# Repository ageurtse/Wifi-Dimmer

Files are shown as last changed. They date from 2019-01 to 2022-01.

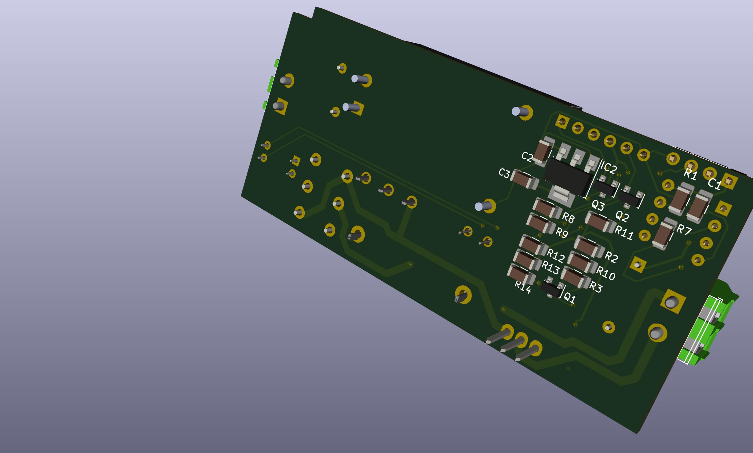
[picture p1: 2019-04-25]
New Dimmer 3d-bottom.jpg

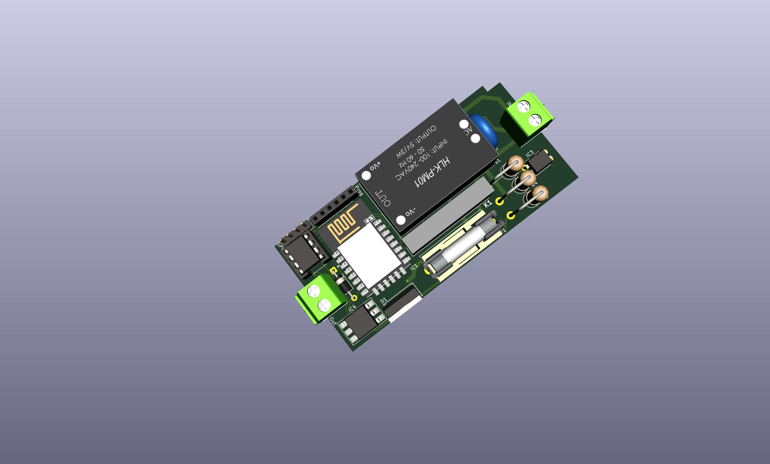
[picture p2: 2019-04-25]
New Dimmer 3d-1.jpg

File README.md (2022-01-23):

# Wifi Dimmer

!!!!! Please do not rebuild this device, in my case there was a serious issue with overheating !!!!!

This is all about my home build WiFi Dimmer
Becaus of it's my first github project, the master is still in Beta. 
For me the project works, but there are a lot off things to change, so keep watching for any change.

11-3-2019, final version, the hard and software is ready to use. 
soon i wil post a youtube movie from live controlling a light. 

3d view 1

This is version 2, in the past i build a differt version which is not exactly what i want. 
Version 2 is one which fit in a simpel housing. 

There are 2 parts of the software, one for the ATTiny and one for the ESP8266
Both are posted here. 
# Word of Caution
Please be very carefull you are working with live voltage 230V, this voltage can realy harm you. 
By building the dimmer, i'm not responsible for any faults or what ever. I stoped development off this dimmer, on one night the triax was overheated. luckely i was at home to prevented real major damage. 

# ATtiny85 Software
The ATtiny85 software is for the soul purpose of dimming the light, there is a zerocross detction which is on interupt 0, the gate is on pin PB3. 
The communication with the main processor is done by softserial. 
The code is based on the forum post at arduino : https://forum.arduino.cc/index.php?topic=314773.0

# ESP8266 software
The main software for the ESP12 module is build with arduino, the wifi and custom settings can be done with the great library from Hieromon https://github.com/Hieromon/AutoConnect
After fist flash by serial, all next updates could be down by browser. 
find the IP-adres or host name and add /update to get to the update page. 
To alter wifi setting's and in the futher mqtt settings and i hope a lot more add /_ac

The file makes use of some thirth party library's which can be found here :
AutoConnect : https://github.com/Hieromon/AutoConnect
PageBuilder : https://github.com/Hieromon/PageBuilder
ArduinoJson : https://arduinojson.org/ version 5

# The hardware
For the main board there is a small mistake made with the Triac, there where 2 wires changes. A1 and A2 need to be turned. 
In a next updat of the print i will fix that, for now i just solderd 2 wires and cross connect them to te pcb.

Also the Fuse holder is to large, i bought a pcb fuse now it all fits well.

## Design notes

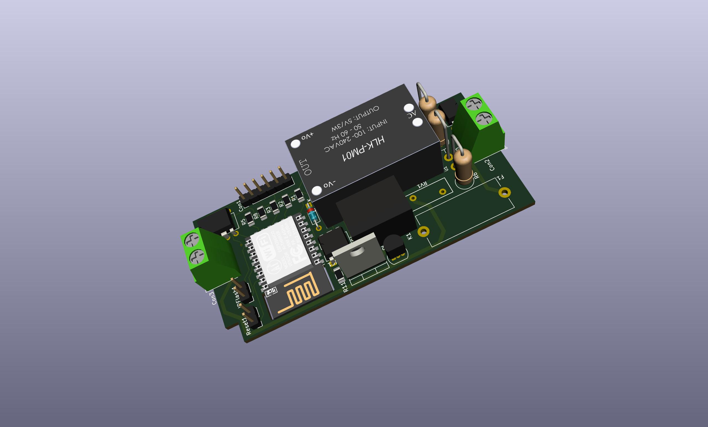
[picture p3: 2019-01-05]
Kicad files/3d view 2.jpg

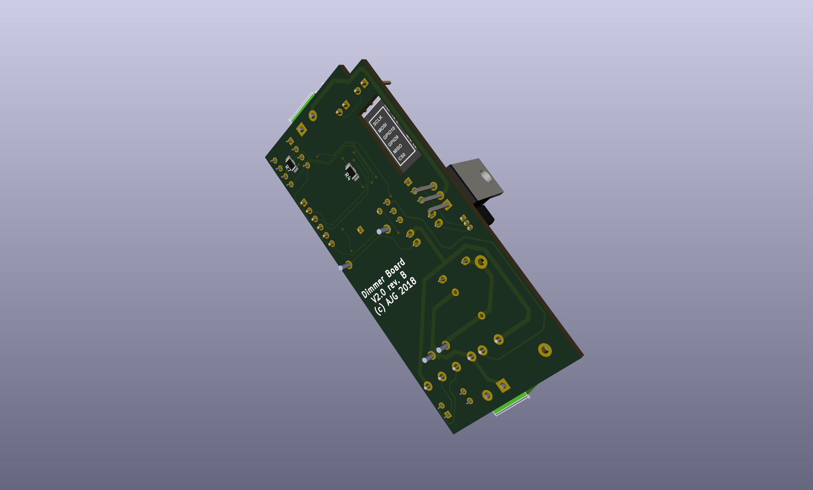
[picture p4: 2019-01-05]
Kicad files/3d view bottom.jpg

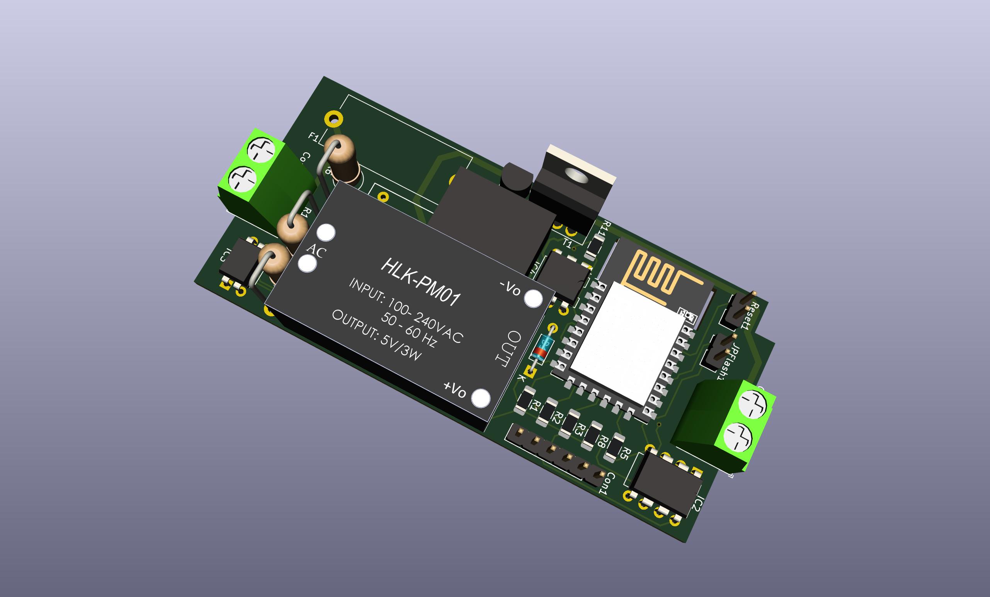
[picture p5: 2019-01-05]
Kicad files/3d view 1.jpg

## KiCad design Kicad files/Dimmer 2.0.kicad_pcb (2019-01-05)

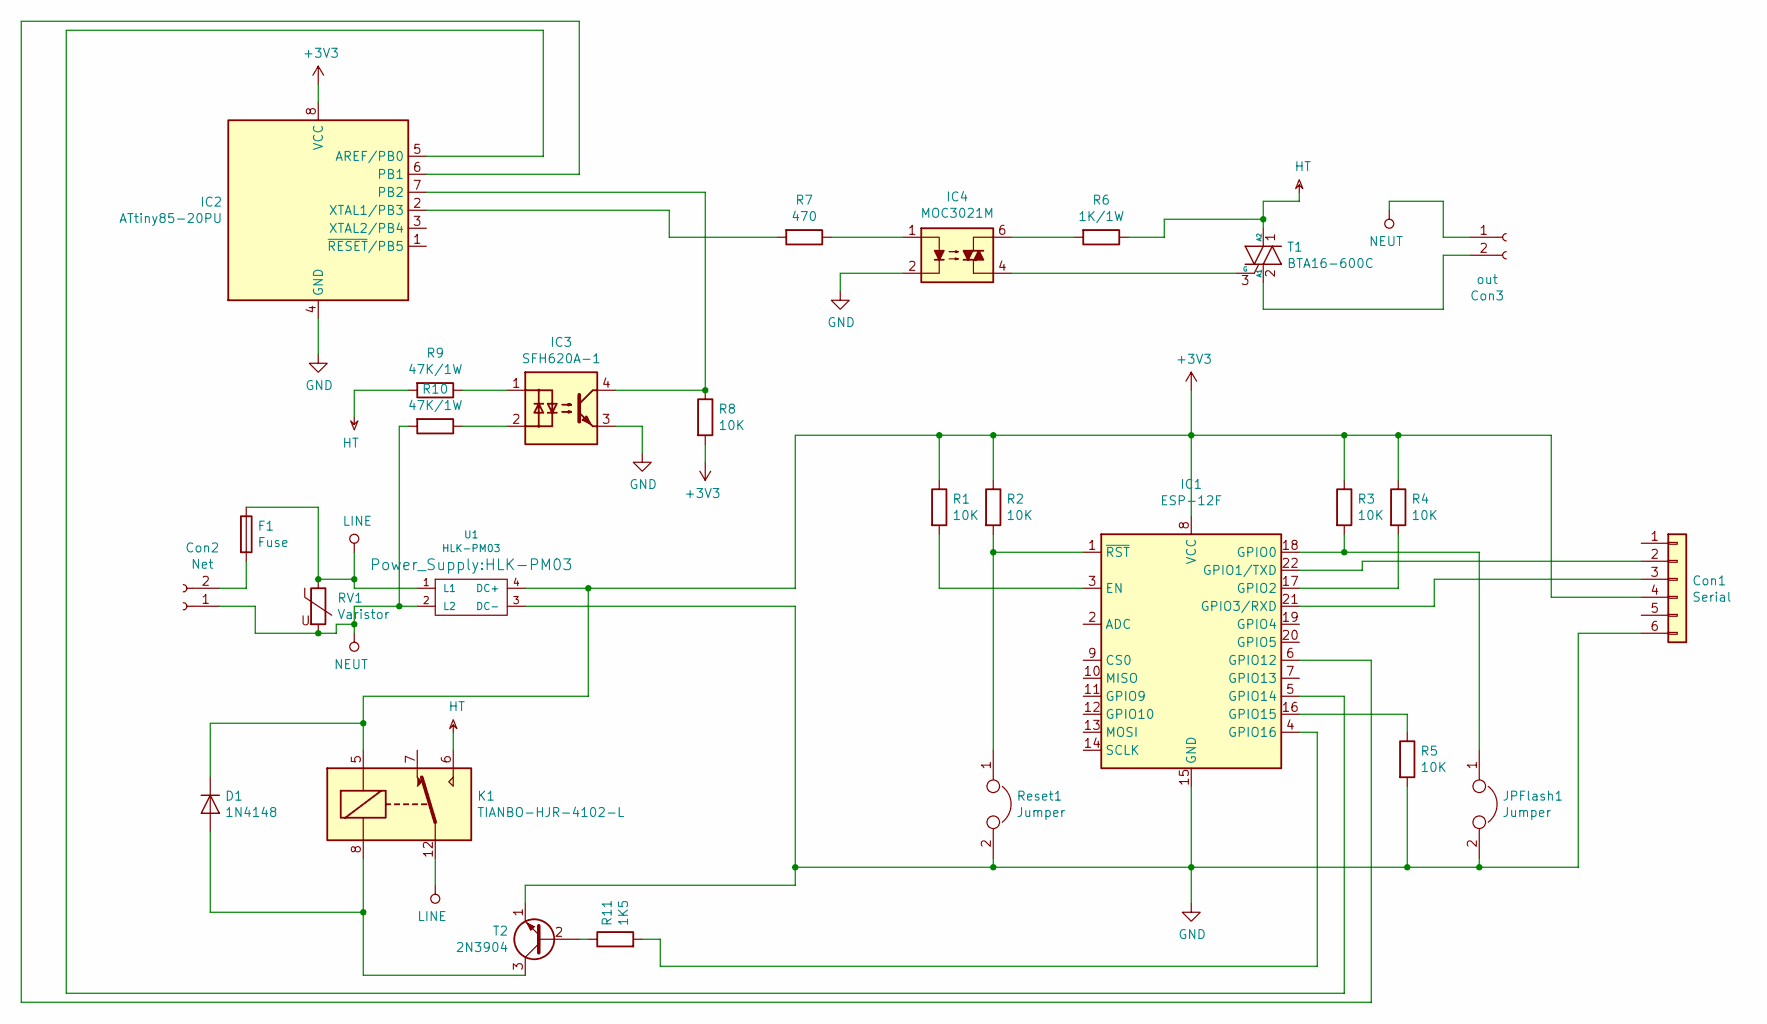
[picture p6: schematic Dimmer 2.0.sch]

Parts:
Con1: Serial; PinHeader_1x06_P2.54mm_Vertical
Con2: Net; TerminalBlock_Phoenix_PT-1,5-2-5.0-H_1x02_P5.00mm_Horizontal
Con3: out; TerminalBlock_Phoenix_PT-1,5-2-5.0-H_1x02_P5.00mm_Horizontal
D1: 1N4148; D_DO-35_SOD27_P7.62mm_Horizontal
F1: Fuse; Fuseholder_Cylinder-5x20mm_Stelvio-Kontek_PTF78_Horizontal_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
IC1: ESP-12F; ESP-12E
IC2: ATtiny85-20PU; DIP-8_W7.62mm
IC3: SFH620A-1; DIP-4_W7.62mm
IC4: MOC3021M; DIP-6_W7.62mm
JPFlash1: Jumper; PinHeader_1x02_P2.54mm_Vertical
K1: TIANBO-HJR-4102-L; Relay_SPDT_HJR-4102
R1, R2, R3, R4, R5, R8: 10K; R_1206_3216Metric_Pad1.42x1.75mm_HandSolder
R6: 1K/1W; R_Axial_DIN0414_L11.9mm_D4.5mm_P5.08mm_Vertical
R7: 470; R_1206_3216Metric_Pad1.42x1.75mm_HandSolder
R9, R10: 47K/1W; R_Axial_DIN0414_L11.9mm_D4.5mm_P5.08mm_Vertical
R11: 1K5; R_1206_3216Metric_Pad1.42x1.75mm_HandSolder
RV1: Varistor; RV_Disc_D12mm_W4.8mm_P7.5mm
Reset1: Jumper; PinHeader_1x02_P2.54mm_Vertical
T1: BTA16-600C; TO-220-3_Vertical
T2: 2N3904; TO-92_Inline
U1: HLK-PM03

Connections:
+3V3: Con1.4, D1.1 (K), IC1.8 (VCC), IC2.8 (VCC), K1.5, R1.1, R2.1, R3.1, R4.1, R8.2, U1.4 (DC+)
GND: Con1.6, IC1.15 (GND), IC2.4 (GND), IC3.3, IC4.2, JPFlash1.2, R5.2, Reset1.2, T2.1 (E), U1.3 (DC-)
HT: K1.6, R6.1, R9.2, T1.1 (A2)
LINE: F1.1, K1.12, RV1.1, U1.1 (L1)
NEUT: Con2.1, Con3.1, R10.2, RV1.2, U1.2 (L2)
unnamed: Con1.2, IC1.22 (GPIO1/TXD)
unnamed: Con1.3, IC1.21 (GPIO3/RXD)
unnamed: Con2.2, F1.2
unnamed: Con3.2, T1.2 (A1)
unnamed: D1.2 (A), K1.8, T2.3 (C)
unnamed: IC1.1 (~RST), R2.2, Reset1.1
unnamed: IC1.3 (EN), R1.2
unnamed: IC1.4 (GPIO16), R11.2
unnamed: IC1.5 (GPIO14), IC2.5 (AREF/PB0)
unnamed: IC1.6 (GPIO12), IC2.6 (PB1)
unnamed: IC1.16 (GPIO15), R5.1
unnamed: IC1.17 (GPIO2), R4.2
unnamed: IC1.18 (GPIO0), JPFlash1.1, R3.2
unnamed: IC2.2 (XTAL1/PB3), R7.2
unnamed: IC2.7 (PB2), IC3.4, R8.1
unnamed: IC3.1, R9.1
unnamed: IC3.2, R10.1
unnamed: IC4.1, R7.1
unnamed: IC4.4, T1.3 (G)
unnamed: IC4.6, R6.2
unnamed: R11.1, T2.2 (B)

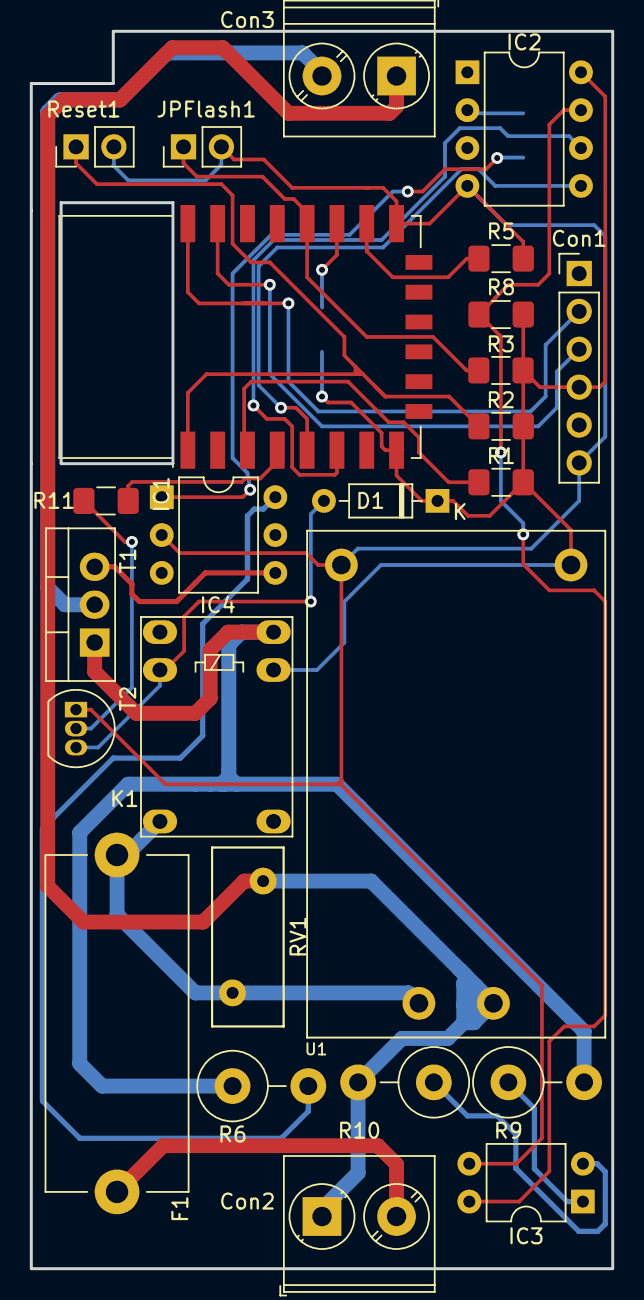
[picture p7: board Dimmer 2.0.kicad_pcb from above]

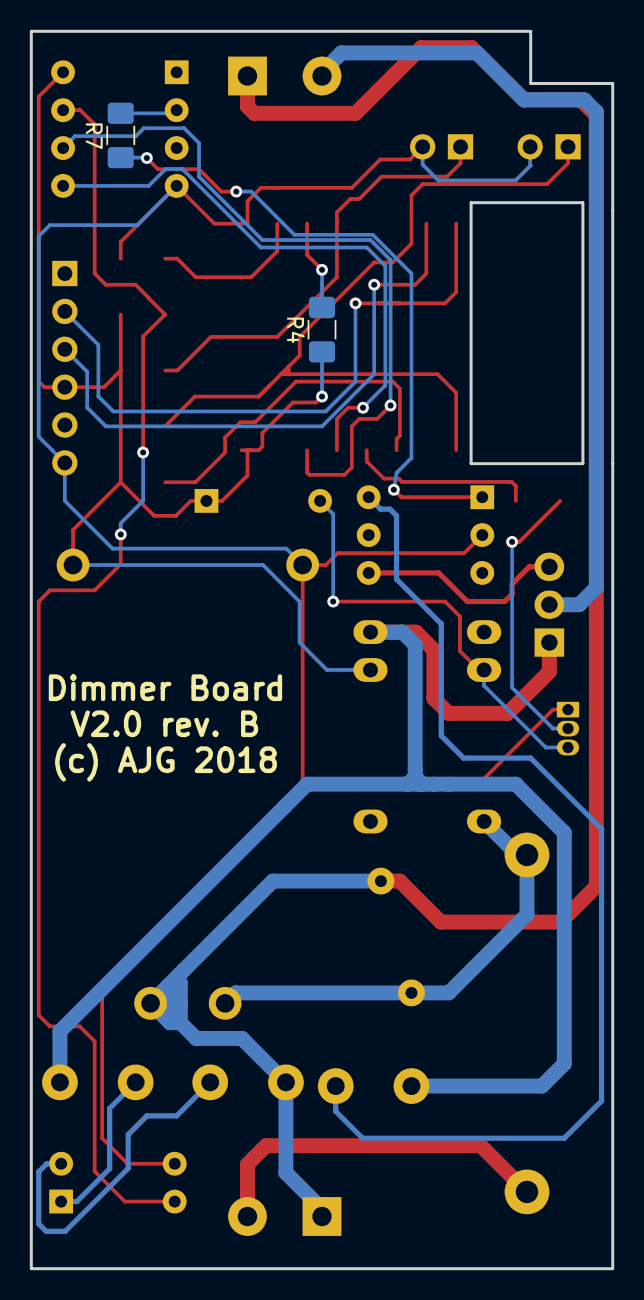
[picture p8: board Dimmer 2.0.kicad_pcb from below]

Board: 2 copper layers, 39.0 x 83.0 mm, 27 parts (2 on the bottom side), 26 nets.

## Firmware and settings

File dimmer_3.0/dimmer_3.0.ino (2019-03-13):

#include <ESP8266WiFi.h>
#define GET_CHIPID()  (ESP.getChipId())
#include <ESP8266HTTPUpdateServer.h>
#include <PubSubClient.h>
#include <AutoConnect.h>
#include <ESP8266HTTPUpdateServer.h>
#include <FS.h>    
#include <SoftwareSerial.h>

#define RX                    14
#define TX                    12
SoftwareSerial DimSerial(RX,TX,false,256); // RX, TX

// ESP8266 webserver
ESP8266WebServer  webServer;
//Autoconnect wifi manager
AutoConnect  portal(webServer);
AutoConnectAux update("/update", "Update");
AutoConnectConfig config;
// MQTT Stuf
WiFiClient   wifiClient;
PubSubClient mqttClient(wifiClient);
// updating
ESP8266HTTPUpdateServer UpdateServer;

#include "declarations.h"
#include "Dimmath.h"
#include "filehandeling.h"
#include "webpages.h"
#include "mqtt.h"

void setup() {
  delay(1000);
  Serial.begin(115200);
  Serial.println();

  pinMode(led_pin, OUTPUT);
  pinMode(relay_pin, OUTPUT);

  //allows serving of files from SPIFFS
  Serial.println("Mounting FS...");
  if (!SPIFFS.begin()) {
    Serial.println("Failed to mount file system");
    return;
  }
  if (loadConfiguration("/config.json", dimconfig)) {
    Serial.println("Config read");
  }
  // Dump config file
  Serial.println(F("Print config file after reading..."));
  printFile(fileName);

  config.apid = String("ESP") + String(GET_CHIPID(), HEX);

  if (dimconfig.devicename != "") {
    config.apid = dimconfig.devicename;
    config.hostName = dimconfig.devicename;
    Serial.println(F("Set custom name"));
  }

  Serial.print("APID : ");
  Serial.println(config.apid);
  
  config.bootUri = AC_ONBOOTURI_HOME;
  config.homeUri = "/";
  
  webServer.on("/saveDim", saveSetting);  // Register /feels handler
  webServer.on("/", handleRoot);
  
  portal.load(settings);
  portal.on("/Settings",settingsOn, AC_EXIT_AHEAD);
  portal.join ({update});
  portal.config(config);

  UpdateServer.setup(&webServer);

  Serial.print("WiFi ");
  if (portal.begin()) {
    Serial.println("connected:" + WiFi.SSID());
    Serial.println("IP:" + WiFi.localIP().toString());
  } else {
    Serial.println("connection failed:" + String(WiFi.status()));
    while (1) {
      delay(100);
      yield();
    }
  }

  if (dimconfig.mqttServer != "") {
    mqttClient.setServer(dimconfig.mqttServer.c_str(), 1883);
    mqttClient.setCallback(callback);  
  }

  digitalWrite(led_pin, HIGH);
  digitalWrite(relay_pin, LOW);
  delay(1000);
  digitalWrite(led_pin, LOW);
  digitalWrite(relay_pin, HIGH);
}


void loop() {
  portal.handleClient();

  if (dimconfig.mqttServer != "") {
    if (!mqttClient.connected()) {
      reconnect();
    }
    mqttClient.loop();
  }
}

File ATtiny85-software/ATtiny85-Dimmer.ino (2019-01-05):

// Voltage controlled dimmer with ATtiny85
//
// This arduino sketch includes a zero
// crossing detect function and an opto-isolated triac.
//
// AC Phase control is accomplished using the internal
// hardware timer1 in the ATtiny85
//
// Timing Sequence
// * timer is set up but disabled
// * zero crossing detected
// * timer starts counting from zero
// * comparator set to "delay to on" value
// * counter reaches comparator value
// * comparator ISR turns on triac gate
// * counter set to overflow - pulse width
// * counter reaches overflow
// * overflow ISR turns off triac gate
// * triac stops conducting at next zero cross

// The hardware timer runs at 1MHz (3mA).
// A half period of a 50Hz AC signal takes 10 ms is 10000 counts.
// @ 1MHZ (3ma)prescaler (1000) 128 78 counts per half period

#include <avr/io.h>
#include <avr/interrupt.h>
#include <SoftwareSerial.h>


#define DETECT PB2      //zero cross detect, interrupt 0
#define GATE PB3        //triac gate is physical
#define PULSE 4       	//trigger pulse width 4

#define RX    PB1   		//Serial port RX
#define TX    PB0   		//Serial port TX
SoftwareSerial Serial(RX, TX);

int dimvalue;			//After startup, turn off light;

void setup(){

  delay (9000);								//Wait for booting the ESP8266

	// set up pins
  pinMode(DETECT, INPUT);      //zero cross detect
  digitalWrite(DETECT, HIGH);  //enable pull-up resistor
  pinMode(GATE, OUTPUT);       //triac gate control


  //If all goes well, the light will flash several time, to notify the user
  digitalWrite(GATE, HIGH);
  delay(500);
  digitalWrite(GATE, LOW);
  delay(500);
  digitalWrite(GATE, HIGH);
  delay(500);
  digitalWrite(GATE, LOW);
  delay(500);
  digitalWrite(GATE, HIGH);


  // set up Timer1
  TCCR1 = 0;     											// stop timer
  OCR1A = dimvalue;										// set initial dim value
  TIMSK = _BV(OCIE1A) | _BV(TOIE1);  	// interrupt on Compare Match A | enable timer overflow interrupt
  sei();  														// enable interrupts
  // set up zero crossing interrupt
  attachInterrupt(0,zeroCrossingInterrupt, FALLING);   //

  // ***
  // *** Initialize the Serial port
  // ***
  Serial.begin(9600);
  while (!Serial) {
  }
}

//Interrupt Service Routines
void zeroCrossingInterrupt(){
  TCNT1 = 0;   							//reset timer - count from zero
  TCCR1 = B00001000;        // 1000 ajg 0110 for 64 see table 12.5 of the tiny85 datasheet
}

ISR(TIMER1_COMPA_vect){    //comparator match
  if(OCR1A>95){            //send no pulse to triac for low input voltage for 0v output
    return;
  }

	digitalWrite(GATE,HIGH); //set triac gate to high
  TCNT1 = 255-PULSE;       //trigger pulse width, when TCNT1=255 timer1 overflows
}

ISR(TIMER1_OVF_vect){ 			//timer1 overflow
  digitalWrite(GATE,LOW);   //turn off triac gate
  TCCR1 = 0;                //disable timer stop unintended triggers
}

void loop(){
  if (Serial.available()) {
    // read the most recent byte (which will be from 0 to 100, so it's in %):
  	dimvalue = Serial.read();
  	OCR1A = dimvalue;
  }
}

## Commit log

2019-01-05 Create ATtiny85-Dimmer
    First release of the ATtiny dimmer software, it is based on software from this topic at arduino forum : https://forum.arduino.cc/index.php?topic=314773.0
2019-01-05 Power on, Light off
    Final attiny software.
    The light will now go off after the module is powerd up.
2019-01-05 Add Kicad Project files
    All my current Kicad files
    [Dimmer 2.0.kicad_pcb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]
2019-01-05 Made relais switch
    If minimal dim is reached, turn off power by switching relais off, else turn on relais.
    In a next relais, if relais is turned on, gif a max puls for led lights
2019-03-08 Rewrite project with arduino
    Rewrite project with Arduino
    The esp8266 files are in Dimmer_3.0
2019-03-08 Small changes
    When first flash, the config file is now correct created.
    When a device name is set, this is also the hostename.
    [FileHandeling.h, dimmer_3.0.ino]
2019-04-25 New developed board.
